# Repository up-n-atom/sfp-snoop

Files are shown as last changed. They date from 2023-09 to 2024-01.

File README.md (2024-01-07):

# sfp-snoop

SFP(+) cape for the [VCC-GND](https://vcc-gnd.com) [YD-RP2040](http://152.32.187.208:8080/yd-data/YD-RP2040/) pending a few modifications.

sfp-snoop-pcbdraw-front sfp-snoop-pcbdraw-back

## Necessary YD-RP2040 Modifications

1. __Remove__ *D2, F1, U1, C1, C2*
2. __Bridge__ *D2* pins 1 and 2 with a 0Ohm 0603 resistor

__U1__ *(ME6215C33M5G)* and supporting components on the YD-RP2040 are replaced by __U1__ *(AIC1221-33GY3TR)* on the sfp-snoop 

YD-RP2040-RP2040-vcc-gnd-studio-Micropython-CircuitPython-Arduino-Raspberry-Pi-Pico-PLUS-MCU-Board-microcontroller

## Pinout

| YD-RP2040 | [SFP (INF-8074i)](https://members.snia.org/document/dl/26184) | Transceivers |
| -- | -- | -- |
| 7 (GP5 - *USART1 RX*) | 2 | Huawei SmartAX MA5671A, Alcatel-Lucent G-010S-P, BFW WAS-110 UART TX |
| 12 (GP8 - *USART1 TX*)  | 3 | Nokia G-010S-A UART RX |
| 9 (GP6 - *I2C1 SDA*) | 4 | |
| 10 (GP7 - *I2C1 SCL*) | 5 | |
| 11 (GP9 - *USART1 RX*)  | 6 | Nokia G-010S-A UART TX |
| 6 (GP4 - *USART1 TX*) | 7 | Huawei SmartAX MA5671A, Alcatel-Lucent G-010S-P, BFW WAS-110 UART RX |
| 5 (GP3) | 8 | |
| 29 (GP22) | 9 | |

* Short JP1
* Short R10 jumper to pin 37 (GP23) for user button power switch, or populate R10 with a 10KOhm 0603 resistor to access RGB LED (GP23)

## Bill of Materials

Total cost for single unit, incl. YD-RP2040 is around $5 USD.

| Ref. | Value  | [LCSC](https://www.lcsc.com/) | Qty. |
| -- | -- | -- | --:  |
| C1, C2 | 4.7uF  | [C1872](https://www.lcsc.com/product-detail/Multilayer-Ceramic-Capacitors-MLCC-SMD-SMT_Samsung-Electro-Mechanics-CL31B475KAHNNNE_C1872.html) | 2 |
| C3, C6, C9, C11 | 0.1uF  | [C282519](https://www.lcsc.com/product-detail/Multilayer-Ceramic-Capacitors-MLCC-SMD-SMT_CCTC-TCC0603X7R104K500CT_C282519.html) | 4 |
| C4 | 150uF | [C542620](https://www.lcsc.com/product-detail/Tantalum-Capacitors_PANASONIC-6TPE150MAPB_C542620.html) | 1 |
| C7, C10 | 1uF | [C59302](https://www.lcsc.com/product-detail/Multilayer-Ceramic-Capacitors-MLCC-SMD-SMT_FH-Guangdong-Fenghua-Advanced-Tech-0603B105K250NT_C59302.html) | 2 |
| C5, C8 | 0.01uF | [C525264](https://www.lcsc.com/product-detail/Multilayer-Ceramic-Capacitors-MLCC-SMD-SMT_PSA-Prosperity-Dielectrics-FN18X103K500PSG_C525264.html) | 2 |
| F1 | 2A | [C261954](https://www.lcsc.com/product-detail/Resettable-Fuses_TLC-Electronic-TLC-NSMD100_C261954.html) | 1 |
| J1 | SFP+ | [C210158](https://www.lcsc.com/product-detail/Card-Edge-Connectors_TE-Connectivity-1367073-1_C210158.html) | 1 |
| J1 (Optional) | SFP+ Cage | [C7429382](https://www.lcsc.com/product-detail/Connector-Shells_HCTL-HC-SFP-03L_C7429382.html) | 1 |
| R1-R10 | 10KOhm | [C25804](https://www.lcsc.com/product-detail/Chip-Resistor-Surface-Mount_UNI-ROYAL-Uniroyal-Elec-0603WAF1002T5E_C25804.html) | 9 |
| U1 | AIC1221-33GY3TR | [C211622](https://www.lcsc.com/product-detail/Linear-Voltage-Regulators-LDO_AIC-Analog-Integrations-AIC1221-33GY3TR_C211622.html) | 1 |
| U2 | AP2191WG-7 | [C141321](https://www.lcsc.com/product-detail/Power-Distribution-Switches_Diodes-Incorporated-AP2191WG-7_C141321.html) | 1 |

| Ref. | Value  | [AliExpress](https://www.aliexpress.com/) | Qty. |
| -- | -- | -- | --:  |
| J2, J3 *sfp-snoop* | Female | [2.54mm pitch, 20-pin Female Header](https://www.aliexpress.com/item/4000386969080.html) | 1 |

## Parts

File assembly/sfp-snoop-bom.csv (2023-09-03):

Reference | Value | Footprint | Datasheet | LCSC | Qty
C1, C2 | 4.7uF | Capacitor_SMD:C_1206_3216Metric | ~ | C1872 | 2
C3, C6, C9, C11 | 0.1uF | Capacitor_SMD:C_0603_1608Metric | ~ | C282519 | 4
C4 | 150uF | Capacitor_Tantalum_SMD:CP_EIA-3528-21_Kemet-B | ~ | C542620 | 1
C5, C8 | 1uF | Capacitor_SMD:C_0603_1608Metric | ~ | C59302 | 2
C7, C10 | 0.01uF | Capacitor_SMD:C_0603_1608Metric | ~ | C525264 | 2
F1 | Polyfuse_Small | Capacitor_SMD:C_1206_3216Metric | ~ |  | 1
J1 | SFP+ | Connector:Connector_SFP_and_Cage | https://members.snia.org/document/dl/25892 | C210158 | 1
J2, J3 | Conn_01x20 | Connector_PinSocket_2.54mm:PinSocket_1x20_P2.54mm_Vertical | ~ |  | 2
JP1 | Jumper_2_Bridged | Jumper:SolderJumper-2_P1.3mm_Open_TrianglePad1.0x1.5mm | ~ |  | 1
R1-R9 | 10K | Resistor_SMD:R_0603_1608Metric | ~ | C25804 | 9
R10 | R | Resistor_SMD:R_0603_1608Metric | ~ |  | 1
U1 | AIC1221-33GY3TR | Package_TO_SOT_SMD:SOT-223-3_TabPin2 | https://www.analog.com.tw/ImgShow/DS-1221G-03.pdf | C211622 | 1
U2 | AP2191WG-7 | Package_TO_SOT_SMD:SOT-23-5 | https://www.diodes.com/assets/Datasheets/AP2181_91.pdf | C141321 | 1

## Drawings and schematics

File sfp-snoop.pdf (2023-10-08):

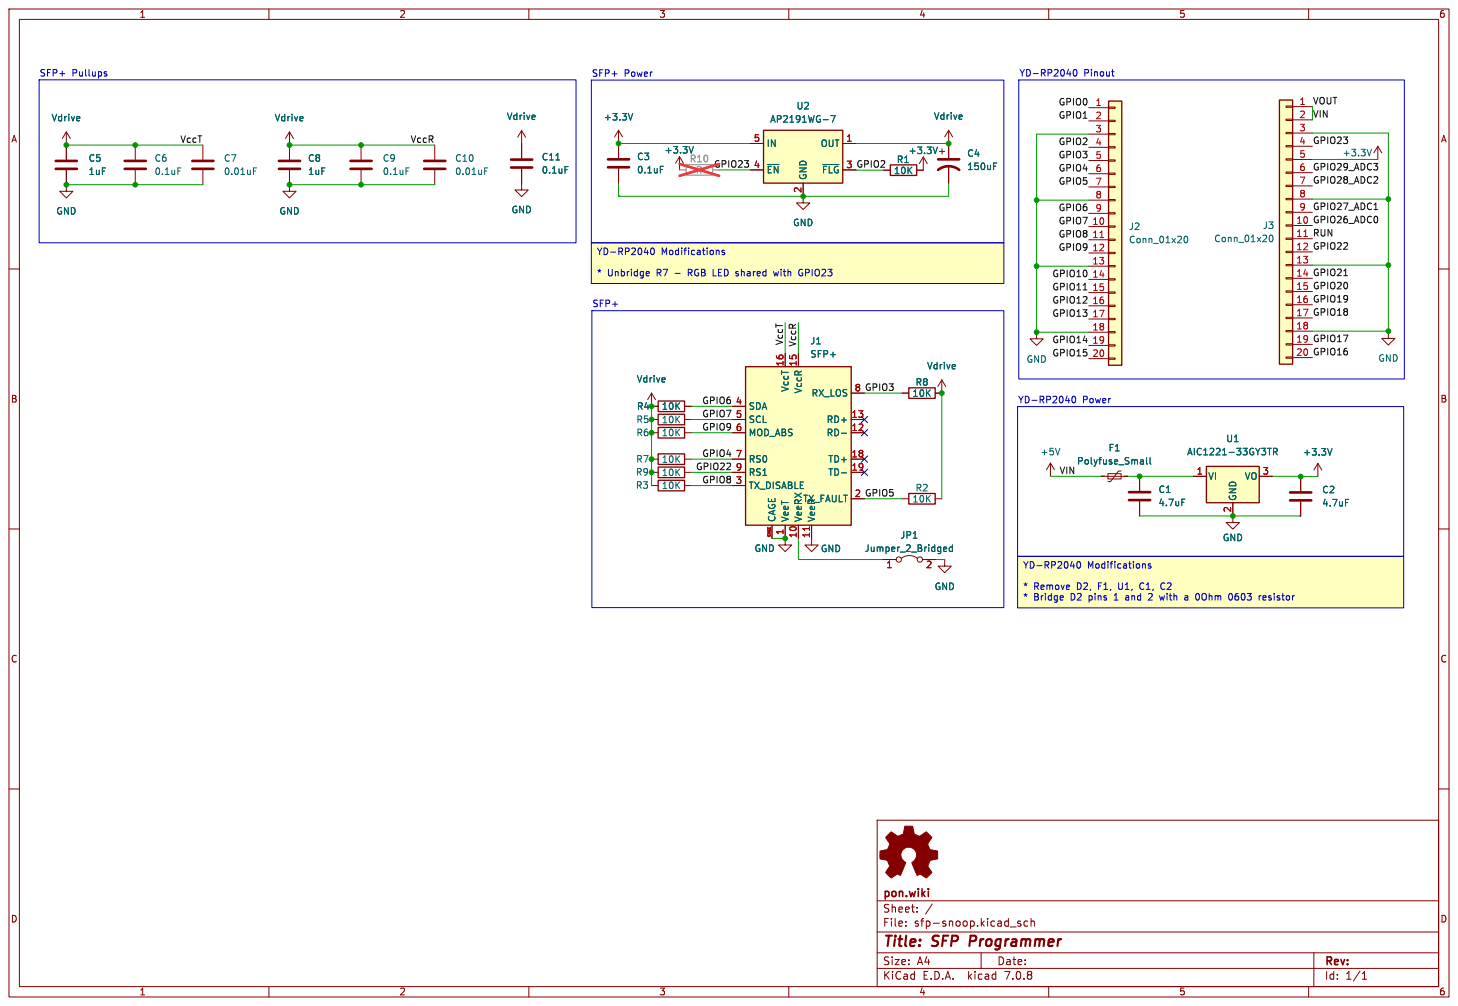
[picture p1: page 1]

* Unbridge R7 - RGB LED shared with GPIO23 C11
0.1uF GND

1 VeeRX 10 VeeR 11 RD- 12 RD+ 13 VccR 15 VccT 16 TD+ 18 TD- 19 TX_FAULT 2 TX_DISABLE 3 SDA 4 SCL 5 MOD_ABS 6 RS0 7 RX_LOS 8 RS1 9 CAGE CAGE J1SFP+

1 VeeRX 10 VeeR 11 RD- 12 RD+ 13 VccR 15 VccT 16 TD+ 18 TD- 19 TX_FAULT 2 TX_DISABLE 3 SDA 4 SCL 5 MOD_ABS 6 RS0 7 RX_LOS 8 RS1 9 CAGE CAGE GND GND

Id: 1/1 Title: SFP Programmer File: sfp-snoop.kicad_sch Sheet: / pon.wiki R2

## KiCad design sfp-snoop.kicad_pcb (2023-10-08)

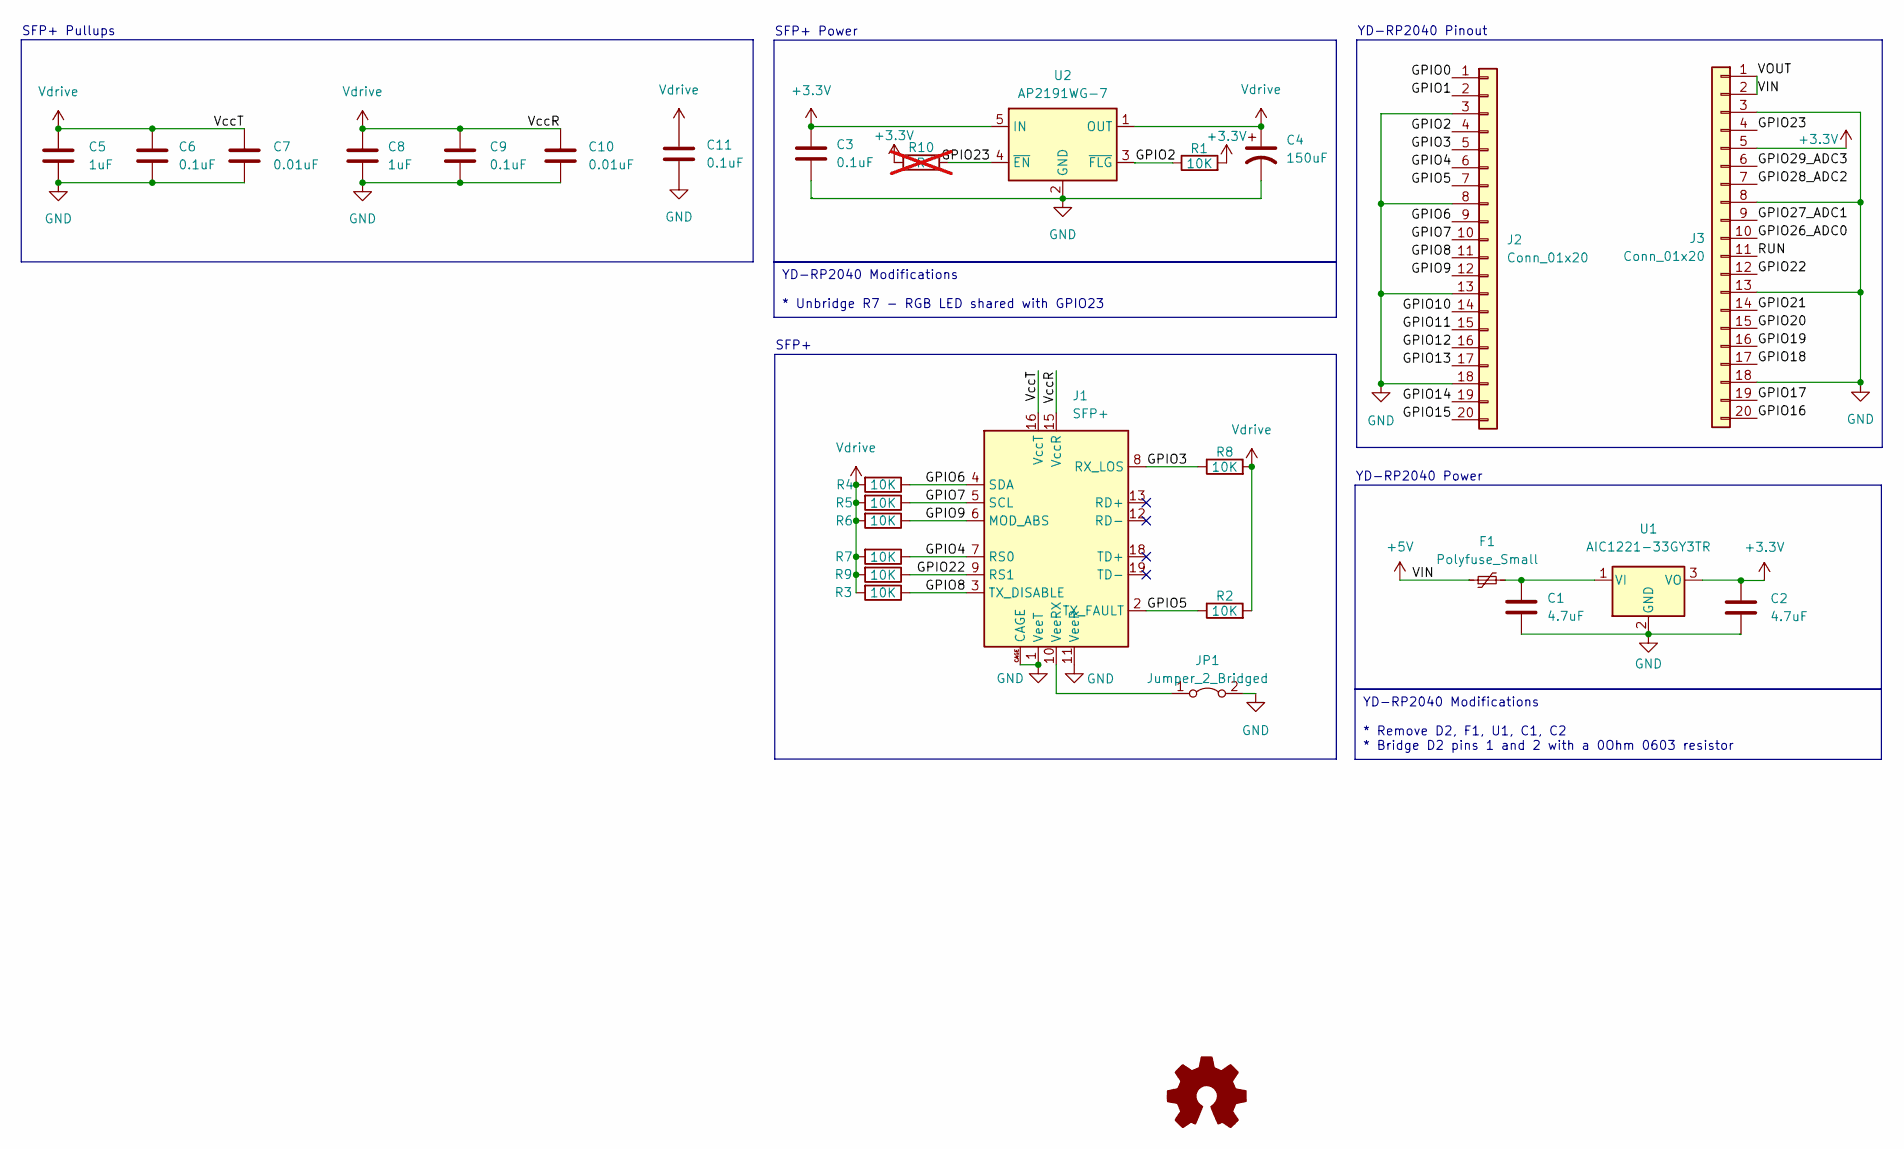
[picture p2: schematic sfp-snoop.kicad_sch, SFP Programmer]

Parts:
C1, C2: 4.7uF; C_1206_3216Metric; LCSC C1872
C3, C6, C9, C11: 0.1uF; C_0603_1608Metric; LCSC C282519
C4: 150uF; CP_EIA-3528-21_Kemet-B; LCSC C542620
C5, C8: 1uF; C_0603_1608Metric; LCSC C59302
C7, C10: 0.01uF; C_0603_1608Metric; LCSC C525264
F1: Polyfuse_Small; C_1206_3216Metric
J1: SFP+; Connector_SFP_and_Cage; LCSC C210158
J2, J3: Conn_01x20; PinSocket_1x20_P2.54mm_Vertical
JP1: Jumper_2_Bridged; SolderJumper-2_P1.3mm_Open_TrianglePad1.0x1.5mm
R1, R2, R3, R4, R5, R6, R7, R8, R9: 10K; R_0603_1608Metric; LCSC C25804
R10: R; R_0603_1608Metric; not fitted
U1: AIC1221-33GY3TR; SOT-223-3_TabPin2; LCSC C211622
U2: AP2191WG-7; SOT-23-5; LCSC C141321

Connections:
+3.3V: C2.1, C3.1, J3.5, R1.2, R10.1, U1.3 (VO), U2.5 (IN)
+5V: F1.1, J3.1, J3.2
/GPIO0: J2.1
/GPIO1: J2.2
/GPIO2: J2.4, R1.1, U2.3 (~FLG)
/GPIO3: J1.8 (RX_LOS), J2.5, R8.1
/GPIO4: J1.7 (RS0), J2.6, R7.1
/GPIO5: J1.2 (TX_FAULT), J2.7, R2.1
/GPIO6: J1.4 (SDA), J2.9, R4.1
/GPIO7: J1.5 (SCL), J2.10, R5.1
/GPIO8: J1.3 (TX_DISABLE), J2.11, R3.1
/GPIO9: J1.6 (MOD_ABS), J2.12, R6.1
/GPIO10: J2.14
/GPIO11: J2.15
/GPIO12: J2.16
/GPIO13: J2.17
/GPIO14: J2.19
/GPIO15: J2.20
/GPIO16: J3.20
/GPIO17: J3.19
/GPIO18: J3.17
/GPIO19: J3.16
/GPIO20: J3.15
/GPIO21: J3.14
/GPIO22: J1.9 (RS1), J3.12, R9.1
/GPIO23: J3.4, R10.2, U2.4 (~EN)
/GPIO26_ADC0: J3.10
/GPIO27_ADC1: J3.9
/GPIO28_ADC2: J3.7
/GPIO29_ADC3: J3.6
/RUN: J3.11
GND: C1.2, C2.2, C3.2, C4.2, C5.2, C6.2, C7.2, C8.2, C9.2, C10.2, C11.2, J1.1 (VeeT), J1.11 (VeeR), J1.14 (VeeR), J1.17 (VeeT), J1.20 (VeeT), J1.CAGE, J2.3, J2.8, J2.13, J2.18, J3.3, J3.8, J3.13, J3.18, JP1.2 (B), U1.2 (GND), U2.2 (GND)
unnamed: J1.10 (VeeRX), JP1.1 (A)
unnamed: C1.1, F1.2, U1.1 (VI)
Vdrive: C4.1, C5.1, C6.1, C7.1, C8.1, C9.1, C10.1, C11.1, J1.15 (VccR), J1.16 (VccT), R2.2, R3.2, R4.2, R5.2, R6.2, R7.2, R8.2, R9.2, U2.1 (OUT)

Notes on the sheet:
YD-RP2040 Modifications * Unbridge R7 - RGB LED shared with GPIO23
YD-RP2040 Modifications * Remove D2, F1, U1, C1, C2 * Bridge D2 pins 1 and 2 with a 0Ohm 0603 resistor
SFP+
SFP+ Pullups
SFP+ Power
YD-RP2040 Pinout
YD-RP2040 Power

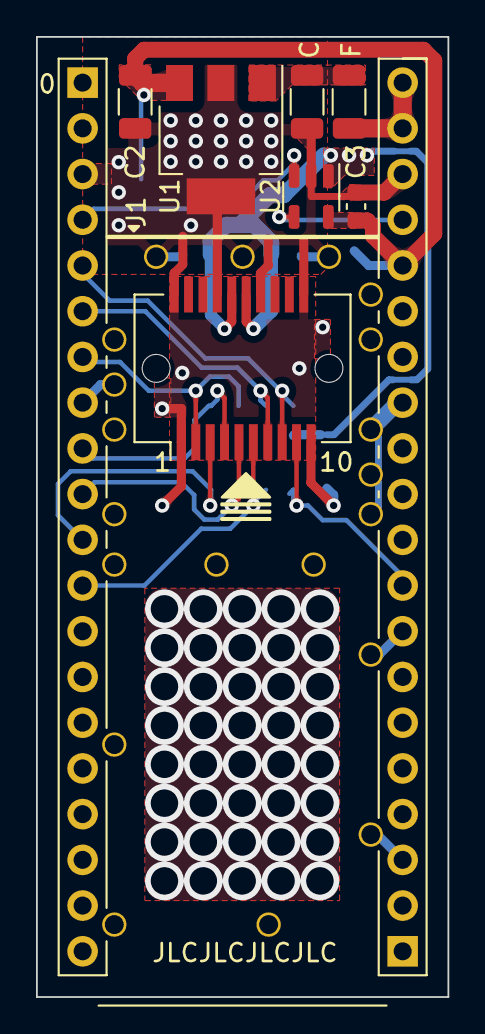
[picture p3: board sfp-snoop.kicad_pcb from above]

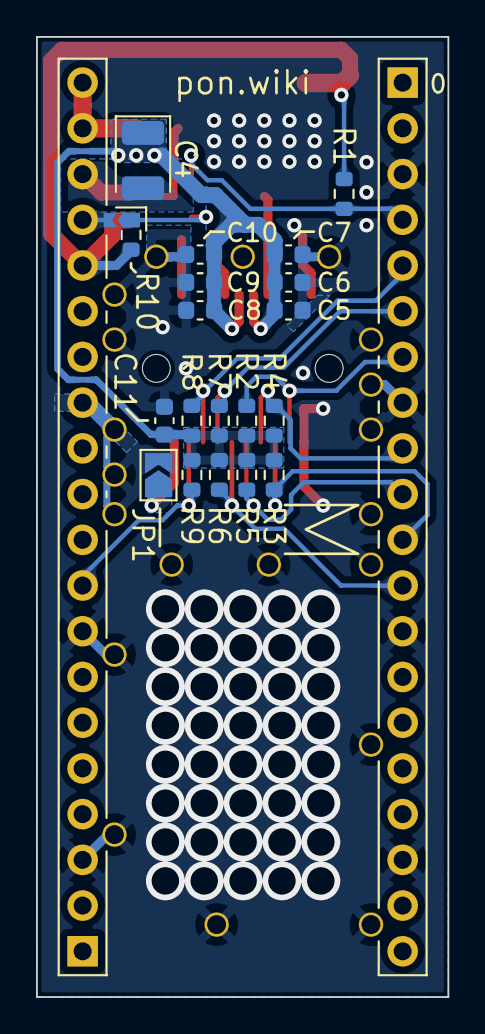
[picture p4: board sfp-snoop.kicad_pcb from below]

Board: 2 copper layers, 22.9 x 53.3 mm, 28 parts (19 on the bottom side), 16 nets.

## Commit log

2023-09-03 Add KiCad files
    [sfp-snoop-bom.csv, sfp-snoop.kicad_pcb, sfp-snoop.kicad_sch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]
2023-09-03 Update README.md
    Add BOM
2023-09-03 Update README.md
    Fix BOM C4 value
2023-09-04 GPIO23 jumper
    [sfp-snoop.kicad_pcb]
2023-09-04 Generate gerbers
    [sfp-snoop-B_Cu.gbl, sfp-snoop-B_Mask.gbs, sfp-snoop-B_Paste.gbp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]
2023-09-04 Update README.md
    Update PcbDraw back render
2023-09-04 Remove extra gerbers
    [sfp-snoop-B_Cu.gbl, sfp-snoop-B_Mask.gbs, sfp-snoop-B_Paste.gbp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]
2023-09-04 Update pcb
    [sfp-snoop.kicad_pcb]
2023-10-08 Update Nokia G-010S-A pinout
    [sfp-snoop-B_Cu.gbl, sfp-snoop-B_Mask.gbs, sfp-snoop-B_Paste.gbp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]
2024-01-07 Update README.md
    Correct capacitor references and remove unnecessary elongated headers
